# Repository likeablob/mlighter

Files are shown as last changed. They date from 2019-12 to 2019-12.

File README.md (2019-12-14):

<p align="center">
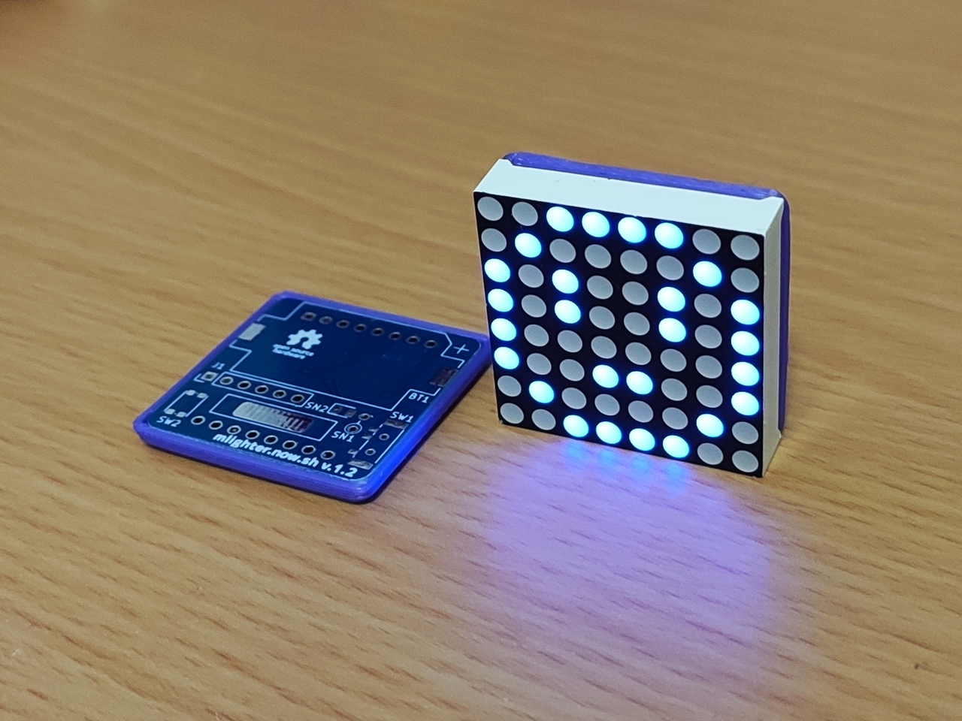
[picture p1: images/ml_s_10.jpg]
  
</p>

# MLIGHTER
[An optically re-writable](https://mlighter.now.sh/) tiny LED badge.

## Project structure
- [`pio/`](./pio) - Source code of the firmware(PlatformIO)
- [`kicad/`](./kicad) - PCB design (KiCad)
- [`openscad/`](./openscad) - Models for the 3D-printable jig. (OpenSCAD)
- https://github.com/likeablob/mlighter-webui - Source code of the Web UI(Nuxt.js + Vuetify)

## Build Instructions
WIP

## BOM
| Name | Description | Amount | Price |
| --- | --- | --- | --- |
| ATiny85 (SOIC) | uC | 1 | ~1 USD  |
| MAX7219 | LED Driver | 1 | 0.2 USD |
| SFH3710 | Photo Transistor | 1 | 0.2 USD |
| 8x8 LED Dot Matrix | (32x32mm) | 1 | ~1 USD  |
| CR2032 | Coin Cell | 1 | - |

## Refs
WIP

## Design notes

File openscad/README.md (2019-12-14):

<p align="center">
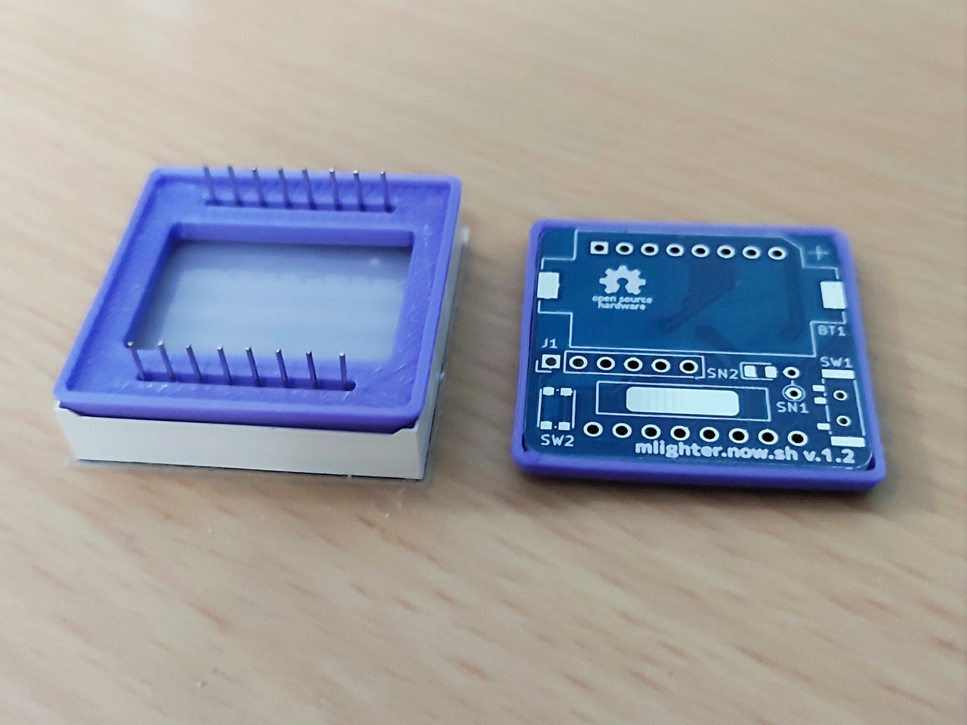
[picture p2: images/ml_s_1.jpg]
  
</p>

## Print conditions
- PLA, 0.2 mm, 180 ℃

## Dependencies
- openscad-nightly (`20181009T230242.gitf3de0e27+2416.1`)
- [OskarLinde]'s [scad-utils](https://github.com/OskarLinde/scad-utils)

## Build
```sh
$ git submodule update --init --recursive # or git clone --recursive
$ make -j4
```

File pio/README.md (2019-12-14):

# MLIGHTER/firmware
It's built on top of [ATTinyCore](https://github.com/SpenceKonde/ATTinyCore).

## Prerequisites
- [PlatformIO](https://platformio.org/)

## Build
- `Ctrl+Alt+B` in your editor, or 
```bash
$ pio run
```

## Upload
- `Ctrl + Alt + U` in your editor, or 
```bash
$ pio run -t upload
```

### ISP port (J1) pin definitions:
| Pin No. | Board |
| --- | --- |
| 1 | 5V |
| 2 | AT_RESET(RST) |
| 3 | AT_PB2_CLK(GPIO0) |
| 4 | GND |
| 5 | AT_PB0_MISO |
| 6 | AT_PB1_MOSI |

### Acknowledgments
- Please refer to
  - [platformio.ini](./platformio.ini)

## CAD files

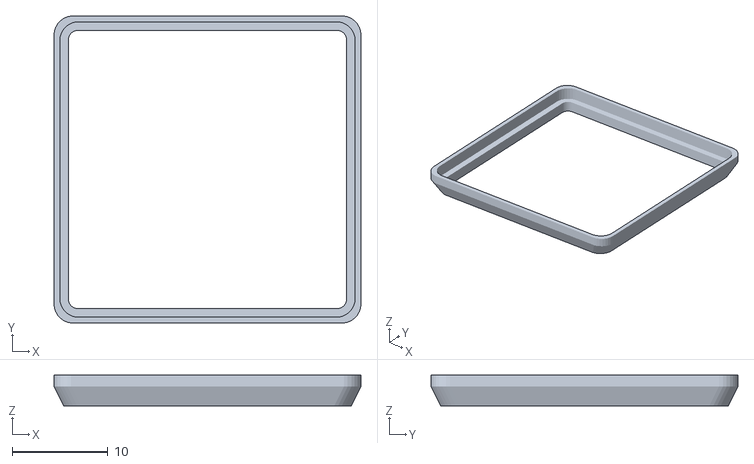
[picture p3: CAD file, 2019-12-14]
openscad/mlighter-shell.stl
32.0 x 32.0 x 3.20

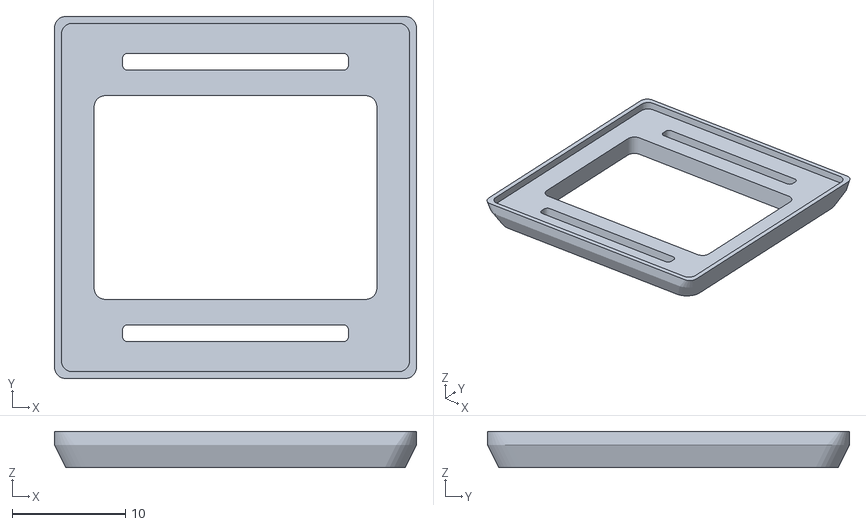
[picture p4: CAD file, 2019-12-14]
openscad/mlighter-jig.stl
32.0 x 32.0 x 3.20

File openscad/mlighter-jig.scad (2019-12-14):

include <scad-utils/mirror.scad>
include <scad-utils/morphology.scad>

$fn=30;

BODY_X=32;
BODY_Y=32;
BODY_Z=3.2;

module jig() {
  difference(){
    hull() {
      translate([0, 0, BODY_Z]) 
      linear_extrude(height=0.001, center=false, convexity=10, twist=0)
      rounding(r=1)
      square(size=[BODY_X, BODY_Y], center=true);

      translate([0, 0, 2]) 
      linear_extrude(height=0.001, center=false, convexity=10, twist=0)
      rounding(r=2)
      square(size=[BODY_X, BODY_Y], center=true);

      linear_extrude(height=0.001, center=false, convexity=10, twist=0)
      rounding(r=2)
      square(size=[BODY_X-2, BODY_Y-2], center=true);    
    }

    linear_extrude(height=BODY_Z*2, center=false, convexity=10, twist=0)
    rounding(r=0.5)
    mirror_y()
    translate([0, 30/2-3, -0.01]) 
    square(size=[20, 1.5], center=true);

    linear_extrude(height=BODY_Z*2, center=false, convexity=10, twist=0)
    rounding(r=1)
    square(size=[25, 18], center=true);

    translate([0, 0, 1.5 + 0.8]) 
    linear_extrude(height=BODY_Z, center=false, convexity=10, twist=0)
    rounding(r=1)
    square(size=[BODY_X-1.2, BODY_Y-1.2], center=true);
  }
}

jig();

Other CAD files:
openscad/mlighter-shell.scad

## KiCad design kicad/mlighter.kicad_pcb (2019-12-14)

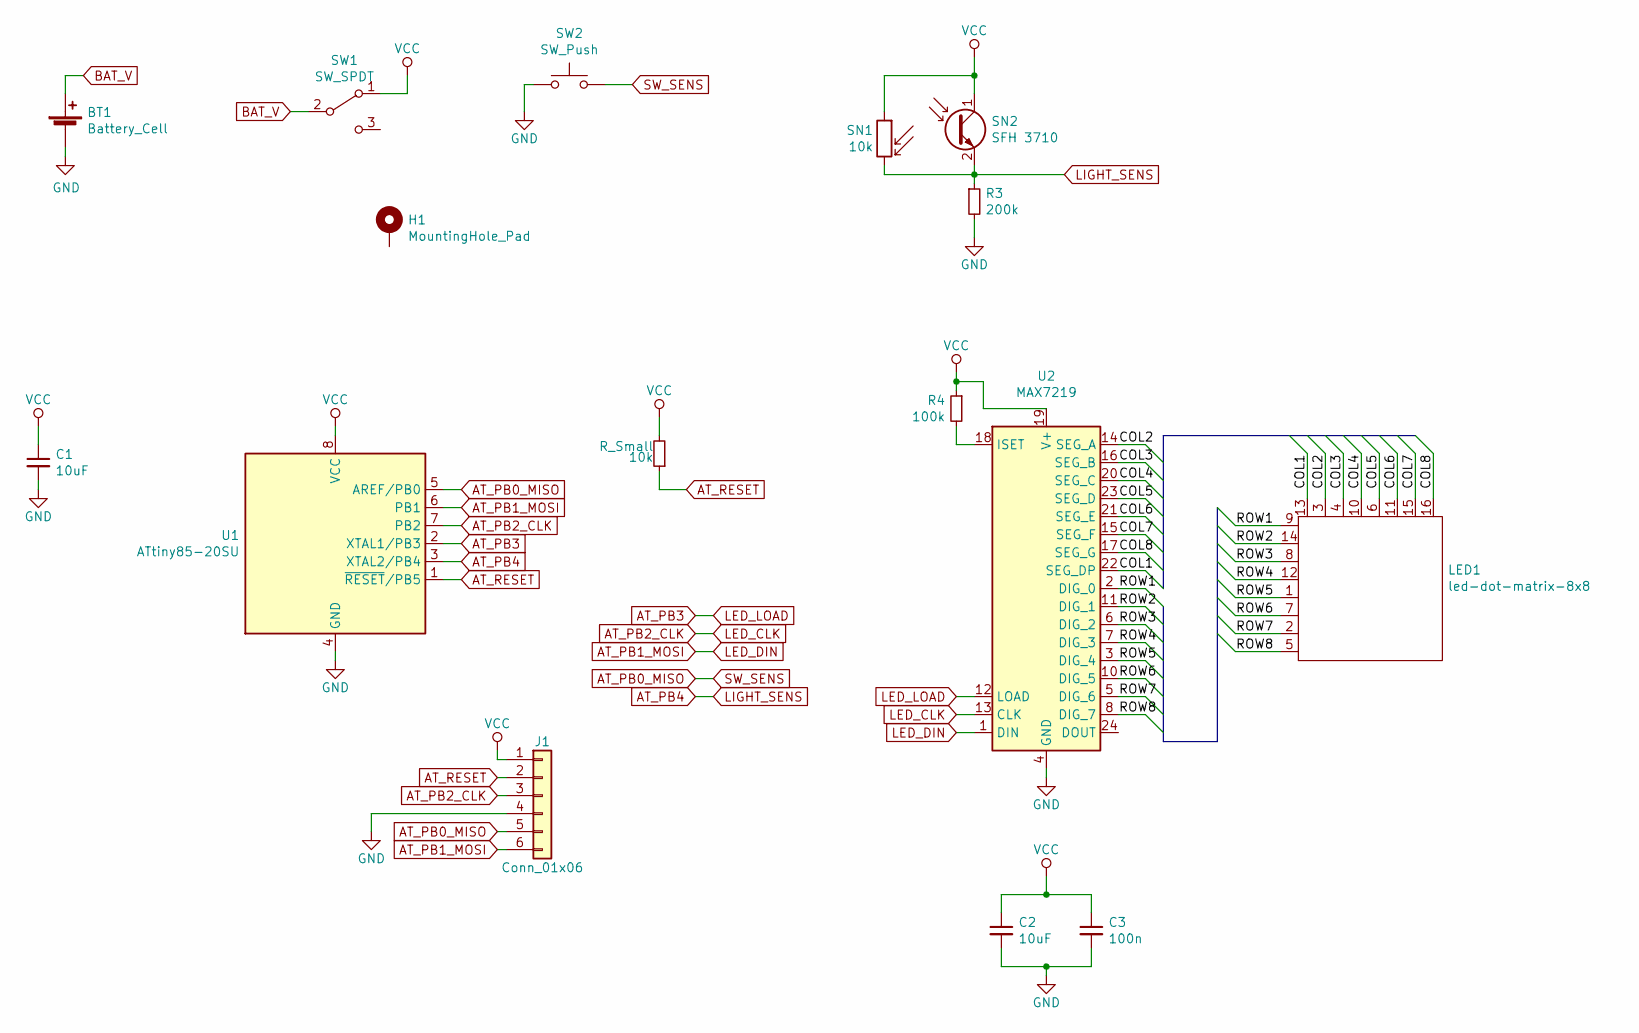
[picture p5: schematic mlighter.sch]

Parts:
10k: R_Small; R_0805_2012Metric
BT1: Battery_Cell; BatteryHolder_Keystone_1060_1x2032_short
C1, C2: 10uF; C_0805_2012Metric_Pad1.15x1.40mm_HandSolder
C3: 100n; C_0805_2012Metric_Pad1.15x1.40mm_HandSolder
H1: MountingHole_Pad; brooch-pin-15mm
J1: Conn_01x06; PinHeader_1x06_P2.54mm_Vertical
LED1: led-dot-matrix-8x8
R3: 200k; R_0805_2012Metric
R4: 100k; R_0805_2012Metric
SN1: 10k; R_Axial_DIN0204_L3.6mm_D1.6mm_P2.54mm_Vertical
SN2: SFH 3710; LED_0805_2012Metric
SW1: SW_SPDT; MSK12C02
SW2: SW_Push; SW_Push_1P1T_NO_CK_KMR2
U1: ATtiny85-20SU; SOIJ-8_5.3x5.3mm_P1.27mm
U2: MAX7219; SOP-24_7.5x15.4mm_P1.27mm

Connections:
/COL1: LED1.13, U2.22 (SEG_DP)
/COL2: LED1.3, U2.14 (SEG_A)
/COL3: LED1.4, U2.16 (SEG_B)
/COL4: LED1.10, U2.20 (SEG_C)
/COL5: LED1.6, U2.23 (SEG_D)
/COL6: LED1.11, U2.21 (SEG_E)
/COL7: LED1.15, U2.15 (SEG_F)
/COL8: LED1.16, U2.17 (SEG_G)
/ROW1: LED1.9, U2.2 (DIG_0)
/ROW2: LED1.14, U2.11 (DIG_1)
/ROW3: LED1.8, U2.6 (DIG_2)
/ROW4: LED1.12, U2.7 (DIG_3)
/ROW5: LED1.1, U2.3 (DIG_4)
/ROW6: LED1.7, U2.10 (DIG_5)
/ROW7: LED1.2, U2.5 (DIG_6)
/ROW8: LED1.5, U2.8 (DIG_7)
AT_PB0_MISO: J1.5, SW2.2, U1.5 (AREF/PB0)
AT_PB1_MOSI: J1.6, U1.6 (PB1), U2.1 (DIN)
AT_PB2_CLK: J1.3, U1.7 (PB2), U2.13 (CLK)
AT_PB3: U1.2 (XTAL1/PB3), U2.12 (LOAD)
AT_PB4: R3.1, SN1.2, SN2.2 (E), U1.3 (XTAL2/PB4)
AT_RESET: 10k.1, J1.2, U1.1 (~RESET~/PB5); also elsewhere on the board
BAT_V: BT1.1 (+), SW1.2 (B)
GND: BT1.2 (-), C1.2, C2.2, C3.2, J1.4, R3.2, SW2.1, U1.4 (GND), U2.4 (GND), U2.9 (GND)
unnamed: R4.2, U2.18 (ISET)
VCC: 10k.2, C1.1, C2.1, C3.1, J1.1, R4.1, SN1.1, SN2.1 (C), SW1.1 (A), U1.8 (VCC), U2.19 (V+); also elsewhere on the board

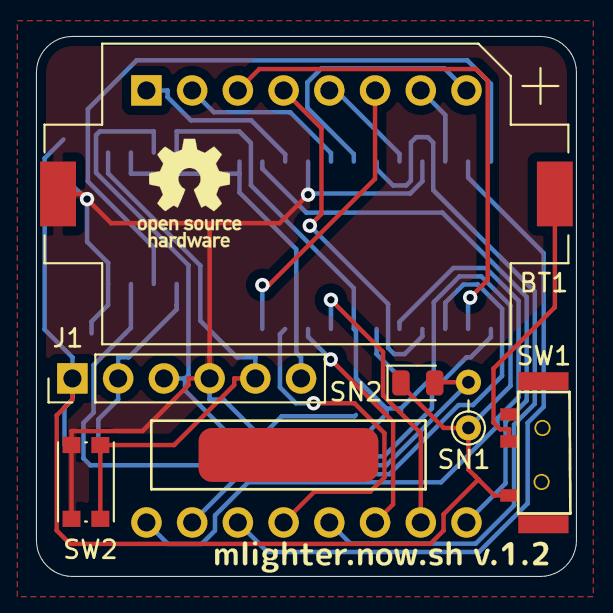
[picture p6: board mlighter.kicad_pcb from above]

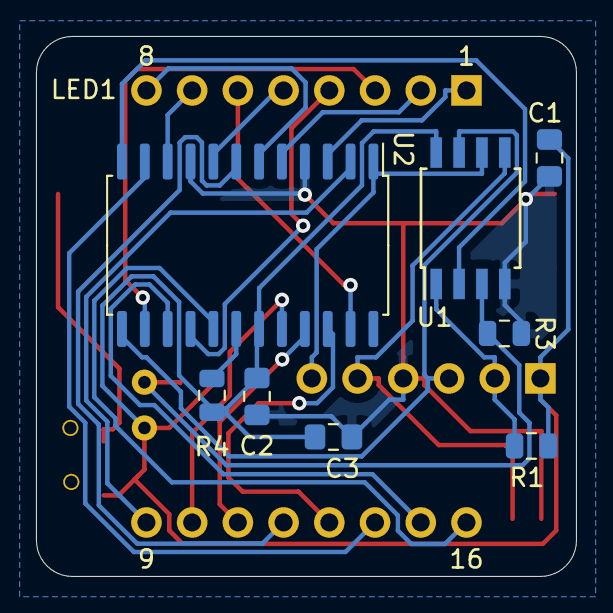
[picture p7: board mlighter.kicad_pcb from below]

Board: 2 copper layers, 30.0 x 30.0 mm, 16 parts (9 on the bottom side), 26 nets.

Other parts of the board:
R1: R_Small; R_0805_2012Metric

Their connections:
AT_RESET: R1.1; also elsewhere on the board
VCC: R1.2; also elsewhere on the board

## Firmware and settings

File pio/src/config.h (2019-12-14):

#pragma once

#define PIN_SW0 PB0
#define PIN_SENS PB4

#define PIN_LED_DATA PB1
#define PIN_LED_CLK PB2
#define PIN_LED_CS PB3

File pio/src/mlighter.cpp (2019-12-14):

#include "mlighter.h"
#include "LedControl.h"
#include <Chrono.h>
#include <EEPROM.h>
#include <SimpleButton.h>

LedControl lc = LedControl(PIN_LED_DATA, PIN_LED_CLK, PIN_LED_CS, 1);
SimpleButton button(PIN_SW0);
Chrono scrollTask;

MLighter::MLighter() {}

void MLighter::begin() {
    lc.shutdown(0, false);
    lc.clearDisplay(0);

    pinMode(PIN_SENS, INPUT);
    button.begin();

    isReadingMode = button.read();
    if(isReadingMode) {
        lc.setIntensity(0, 8);
        memccpy(dispBuff, readModeIcon, sizeof(uint8_t), sizeof(readModeIcon));
        draw();
        blink();
        restartReading();
    } else {
        loadConfig();
        blink();
    }
}

void MLighter::handle() {
    if(isReadingMode) {
        read();
        return;
    }

    if(isScrollEnabled && scrollTask.hasPassed(100)) {
        scrollTask.restart();
        scroll();
    }

    uint32_t duration = button.getDuration();
    if(duration > 1000) { // On long press
        scrollPos = 0;
        isScrollEnabled = !isScrollEnabled;
        draw();
    } else if(duration > 100) { // On short press
        cycleBrightness();
    }
}

void MLighter::draw(uint8_t offset = 0) {
    // Transpose dispBuff for faster drawing
    for(size_t row = 0; row < 8; row++) {
        uint8_t rowByte = 0;
        for(size_t col = 0; col < 8; col++) {
            uint8_t buffCol =
                (offset + col) %
                (DISP_BUFF_SIZE + SCROLL_MARGIN); // Colum index of dispBuffer
            if(buffCol < DISP_BUFF_SIZE) {
                rowByte |= ((dispBuff[buffCol] >> (7 - row)) & 0b1)
                           << (7 - col);
            }
        }
        lc.setRow(0, row, rowByte);
    }
}

void MLighter::scroll() {
    draw((++scrollPos) % (DISP_BUFF_SIZE + SCROLL_MARGIN));
}
void MLighter::cycleBrightness() {
    intensity = (intensity + 5) % 16;
    lc.setIntensity(0, intensity);
    EEPROM[EEPROM_ADDR_BRIGHTNESS] = intensity;
}

void MLighter::blink() {
    for(size_t i = 0; i < 90; i++) {
        uint8_t tmp = sinf(i / 30.0 * PI) * 15;

        lc.setIntensity(0, tmp);
        if(tmp == intensity && i > 60) {
            break;
        }
        delay(10);
    }
}

bool MLighter::isBright() { return digitalRead(PIN_SENS); }

void MLighter::restartReading() {
    readCounter = 0;
    memset(dispBuff, 0, DISP_BUFF_SIZE);
}
void MLighter::read() {
    uint32_t start = millis();
    while(!isBright()) {
        if(millis() - start > RESET_DURATION) {
            restartReading();
        }
    }

    start = millis();
    while(true) {
        bool pulseEnd = true;
        for(size_t i = 0; i < 3; i++) {
            pulseEnd = pulseEnd && !isBright();
            delay(1);
        }
        if(pulseEnd) {
            break;
        }

        if(millis() - start > RESET_DURATION) {
            restartReading();
            return;
        }
    }
    int16_t pulse = millis() - start;
    bool isFinished = false;
    if(WITHIN(pulse, PULSE_WIDTH_A, PULSE_MARGIN)) {
        uint8_t bitPos = readCounter % 8;
        uint8_t bytePos = readCounter / 8;
        dispBuff[bytePos] |= 1 << (7 - bitPos);
        readCounter++;
    } else if(WITHIN(pulse, PULSE_WIDTH_B, PULSE_MARGIN)) {
        readCounter++;
    } else if(WITHIN(pulse, PULSE_WIDTH_C, PULSE_MARGIN)) {
        isFinished = true;
    } else {
        restartReading();
        return;
    }

    draw(); // Draw the intermediate data

    if(isFinished && !(readCounter % 8)) {
        readCounter = 0;
        for(size_t i = 0; i < DISP_BUFF_SIZE; i++) {
            EEPROM[i] = dispBuff[i];
        }
        blink();
        return;
    }

    if(readCounter > DISP_BUFF_BITLEN) { // Something went wrong
        restartReading();
        return;
    }

    static bool enableIndicator = false;
    lc.setLed(0, 7, 7, enableIndicator);
    enableIndicator = !enableIndicator;
}

void MLighter::loadConfig() {
    intensity = EEPROM[EEPROM_ADDR_BRIGHTNESS] % 16;
    lc.setIntensity(0, intensity);

    for(size_t i = 0; i < DISP_BUFF_SIZE; i++) {
        dispBuff[i] = EEPROM[EEPROM_ADDR_BUFF + i];
    }
    draw();
}
